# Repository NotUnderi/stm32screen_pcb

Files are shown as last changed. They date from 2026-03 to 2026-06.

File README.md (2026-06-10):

# stm32screen

PCB designed to fit into a 52mm closure and interface with some car sensors and stuff

<b>10.6.2026</b>
<br>
Ordered PCBs from JLCPCB. Changed made to previous version pictured below these new ones are disposing of the USB connector entirely and with it, the SP0503BAHTG TVS diode, adding a user switch, Adding better labels on the silkscreen, slightly better layout, disposing of THT caps. The board will be powered straight from the car's battery, this allows easier installation and decreases cost and complexity.
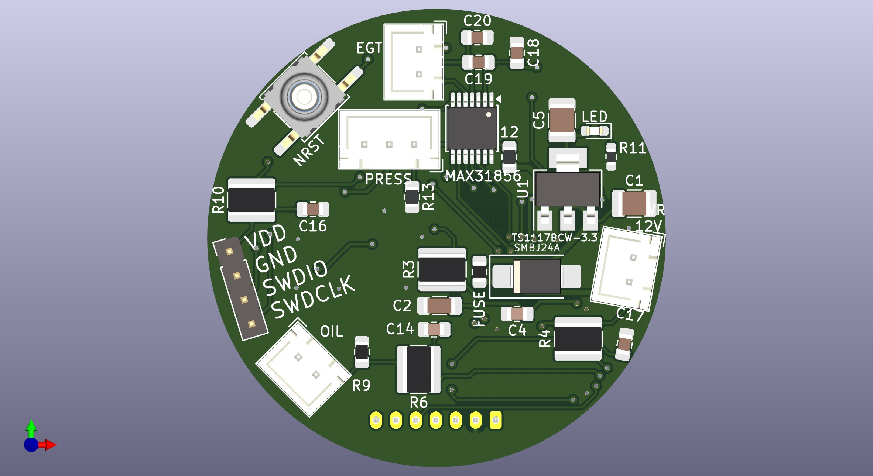
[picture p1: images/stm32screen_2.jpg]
STM32screen PCB F_Cu

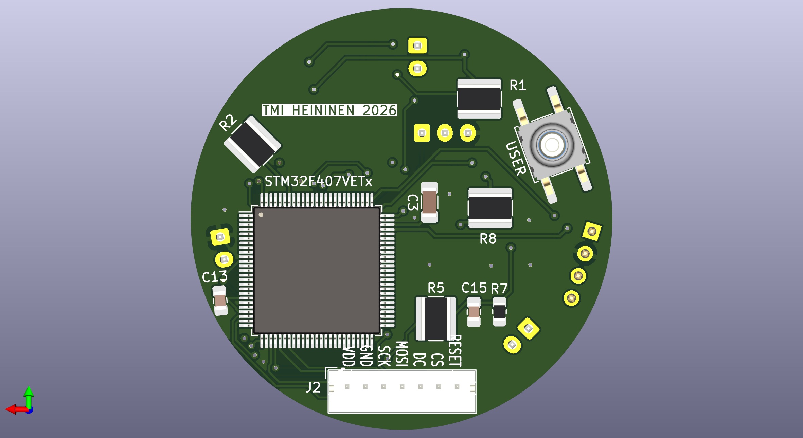
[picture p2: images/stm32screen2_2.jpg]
STM32screen PCB B_Cu


17.3.2026
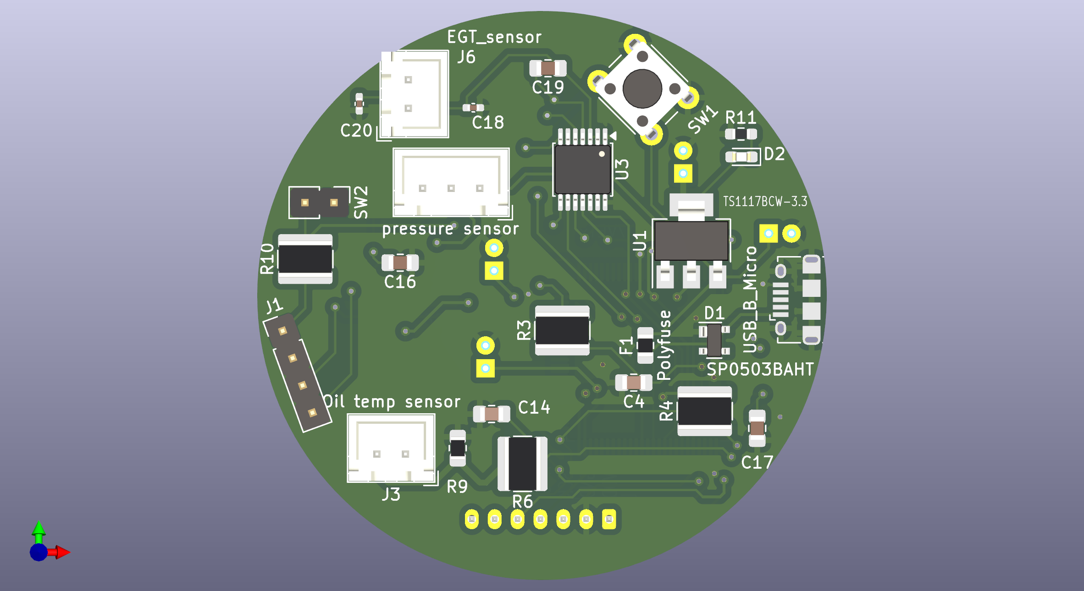
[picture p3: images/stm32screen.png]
STM32screen PCB F_Cu

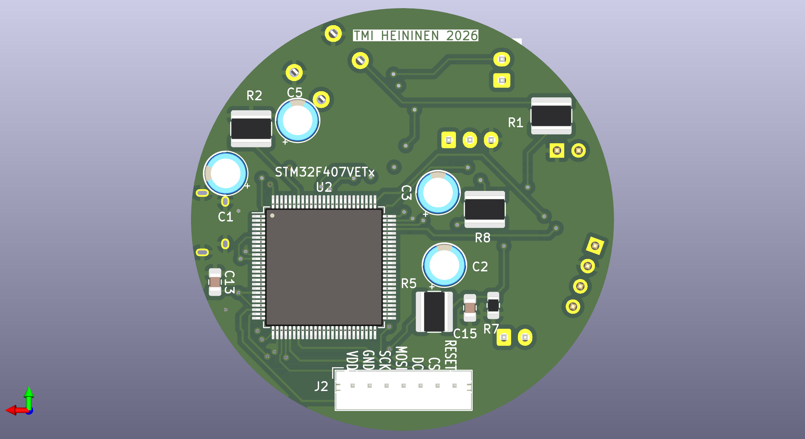
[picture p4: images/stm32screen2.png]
STM32screen PCB B_cu


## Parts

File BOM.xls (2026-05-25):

STM32SCREEN
Mouser No | Mfr. No | Manufacturer | Customer No | Description | RoHS | Lifecycle | Order Qty. | Price (EUR) | Ext.: (EUR)
511-STM32F407VET6 | STM32F407VET6 | STMicroelectronics |  | ARM Microcontrollers - MCU ARM M4 512 FLASH 168 Mhz 192kB SRAM | RoHS Compliant |  | 1 | 9,06 € | 9,06 €
576-SP0503BAHTG | SP0503BAHTG | Littelfuse |  | ESD Protection Diodes / TVS Diodes TVS AVAL DIODE SMT | RoHS Compliant |  | 1 | 0,989 € | 0,99 €
821-TS1117BCW33RPG | TS1117BCW33 RPG | Taiwan Semiconductor |  | LDO Voltage Regulators 1A 3.3V LOW DROPOUT VOLTAGE REGULATOR | RoHS Compliant |  | 1 | 0,327 € | 0,33 €
576-0805L050 | 0805L050WR | Littelfuse |  | Resettable Fuses - PPTC 0.50A 6V 0805 | RoHS Compliant |  | 1 | 2,03 € | 2,03 €
700-MAX31856MUD+ | MAX31856MUD+ | Analog Devices Inc. |  | Sensor Interface Precision Thermocouple to Digital Conver | RoHS Compliant |  | 1 | 11,23 € | 11,23 €
80-C0805F104K1RAUTO | C0805F104K1RACAUTO | KEMET |  | Multilayer Ceramic Capacitors MLCC - SMD/SMT 100V 0.1uF 10% X7R -55 / +125C AEC-Q200 | RoHS Compliant | New Product | 7 | 0,198 € | 1,39 €
71-CRCW121810K0FKEK | CRCW121810K0FKEK | Vishay |  | Thick Film Resistors - SMD 1watt 10Kohms 1% | RoHS Compliant By Exemption |  | 6 | 0,31 € | 1,86 €
71-CRCW1218-10-E3 | CRCW121810R0FKEK | Vishay |  | Thick Film Resistors - SMD 1watt 10ohms 1% | RoHS Compliant By Exemption |  | 2 | 0,43 € | 0,86 €
667-ERA-6APB203V | ERA-6APB203V | Panasonic |  | Thin Film Resistors - SMD 0805 20Kohm 0.1% 15ppm AEC-Q200 | RoHS Compliant |  | 1 | 0,335 € | 0,34 €
594-MCU08050C3300FP5 | MCU08050C3300FP500 | Vishay |  | Thin Film Resistors - SMD MCU 0805-50 1% P5 330R | RoHS Compliant By Exemption |  | 1 | 0,086 € | 0,09 €
179-TS406638R160S | TS40-66-38-R-160-SMT-TR | Same Sky |  | Tactile Switches Tactile Switch, SPST, 6 x 6 mm, 3.8 mm height, 160gf, Red, Surface Mount, TR | RoHS Compliant | New Product | 2 | 0,413 € | 0,83 €
603-SR2512JK-073K3L | SR2512JK-073K3L | YAGEO |  | Thick Film Resistors - SMD 3.3 kOhms 1 W 2512 5 % AEC-Q200 | RoHS Compliant By Exemption |  | 1 | 0,129 € | 0,13 €
720-P4112S2U1252X4X5 | KT EELP41.12-S2U1-25-2X4X-5-R18 | ams OSRAM |  | Single Colour LEDs | RoHS Compliant | New Product | 1 | 0,258 € | 0,26 €
667-ERJ-UP3F1600V | ERJ-UP3F1600V | Panasonic |  | Thick Film Resistors - SMD 0603 0.25W 1% 160ohm AEC-Q200 | RoHS Compliant By Exemption |  | 1 | 0,181 € | 0,18 €
603-CC805KKX5R6BB106 | CC0805KKX5R6BB106 | YAGEO |  | Multilayer Ceramic Capacitors MLCC - SMD/SMT 10V 10uF X5R 0805 10% HI CV | RoHS Compliant |  | 1 | 0,335 € | 0,34 €
77-VJ0805Y103KBBBE31 | VJ0805Y103KBBBE31 | Vishay |  | Multilayer Ceramic Capacitors MLCC - SMD/SMT 0805 10nF 100volts X7R 10% | No |  | 2 | 0,292 € | 0,58 €
603-AA0805FR-134K7L | AA0805FR-134K7L | YAGEO |  | Thick Film Resistors - SMD 4.7k Ohms 1/8 W 0805 1% AEC-Q200 | RoHS Compliant By Exemption |  | 1 | 0,086 € | 0,09 €
910-HDR100IMP40MGVTH | HDR100IMP40M-G-V-TH | Chip Quik |  | PCBs & Breadboards 0.1" 40 pin Vertical Male Header Through Hole Gold | RoHS Compliant |  | 1 | 0,765 € | 0,77 €
306-B7BPHSM4TBLFSN | B7B-PH-SM4-TB(LF)(SN) | JST |  | Headers & Wire Housings PH Series 2 mm Pitch 7 Position SMT Single Row Top Entry Shrouded Header | RoHS Compliant | New Product | 1 | 0,714 € | 0,71 €
306-B2BXHARLFSNP | B2B-XH-A-R(LF)(SN) | JST |  | Headers & Wire Housings XH HEADER (TOP) | RoHS Compliant |  | 3 | 0,138 € | 0,41 €
306-B3BXHAYLFSNP | B3B-XH-A-Y(LF)(SN) | JST |  | Headers & Wire Housings XH HEADER (TOP) | RoHS Compliant | New At Mouser | 1 | 0,181 € | 0,18 €
80-C1206C225K4RAUTO | C1206C225K4RACAUTO | KEMET |  | Multilayer Ceramic Capacitors MLCC - SMD/SMT 16V 2.2uF X7R 1206 10% AEC-Q200 | RoHS Compliant |  | 2 | 0,284 € | 0,57 €

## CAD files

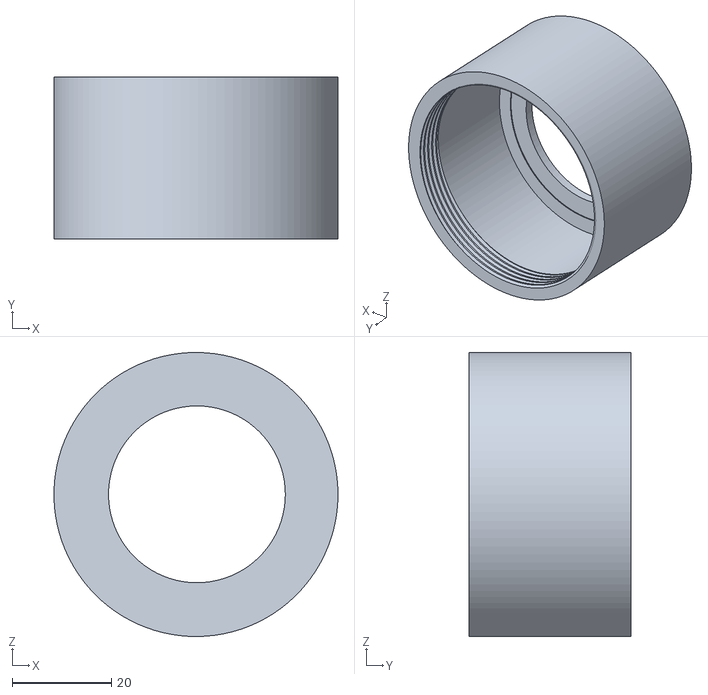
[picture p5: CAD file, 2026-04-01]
case front.stl
57.2 x 32.6 x 57.2

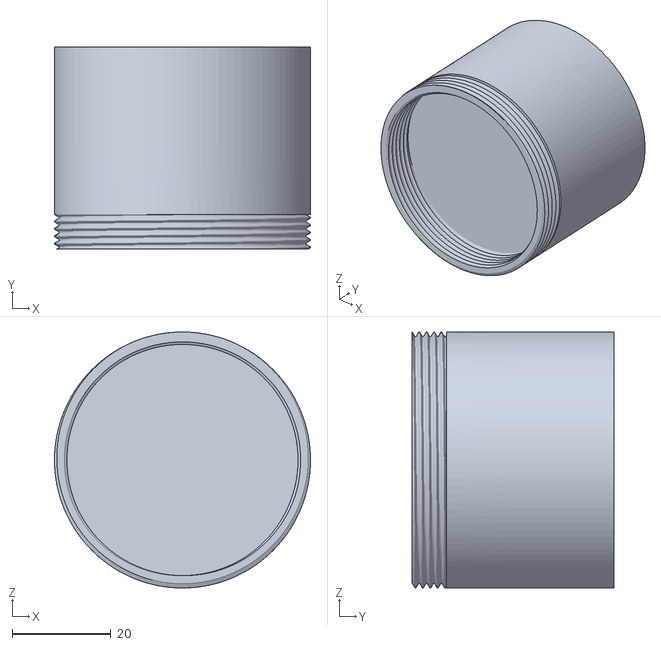
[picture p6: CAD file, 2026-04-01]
case back.stl
51.9 x 41.0 x 51.8

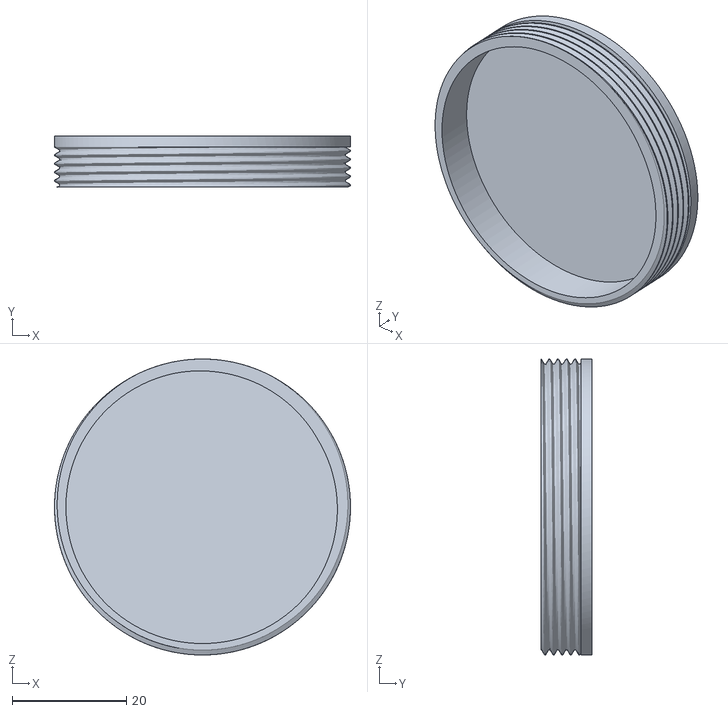
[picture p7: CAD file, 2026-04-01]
case back small.stl
51.8 x 9.00 x 51.8

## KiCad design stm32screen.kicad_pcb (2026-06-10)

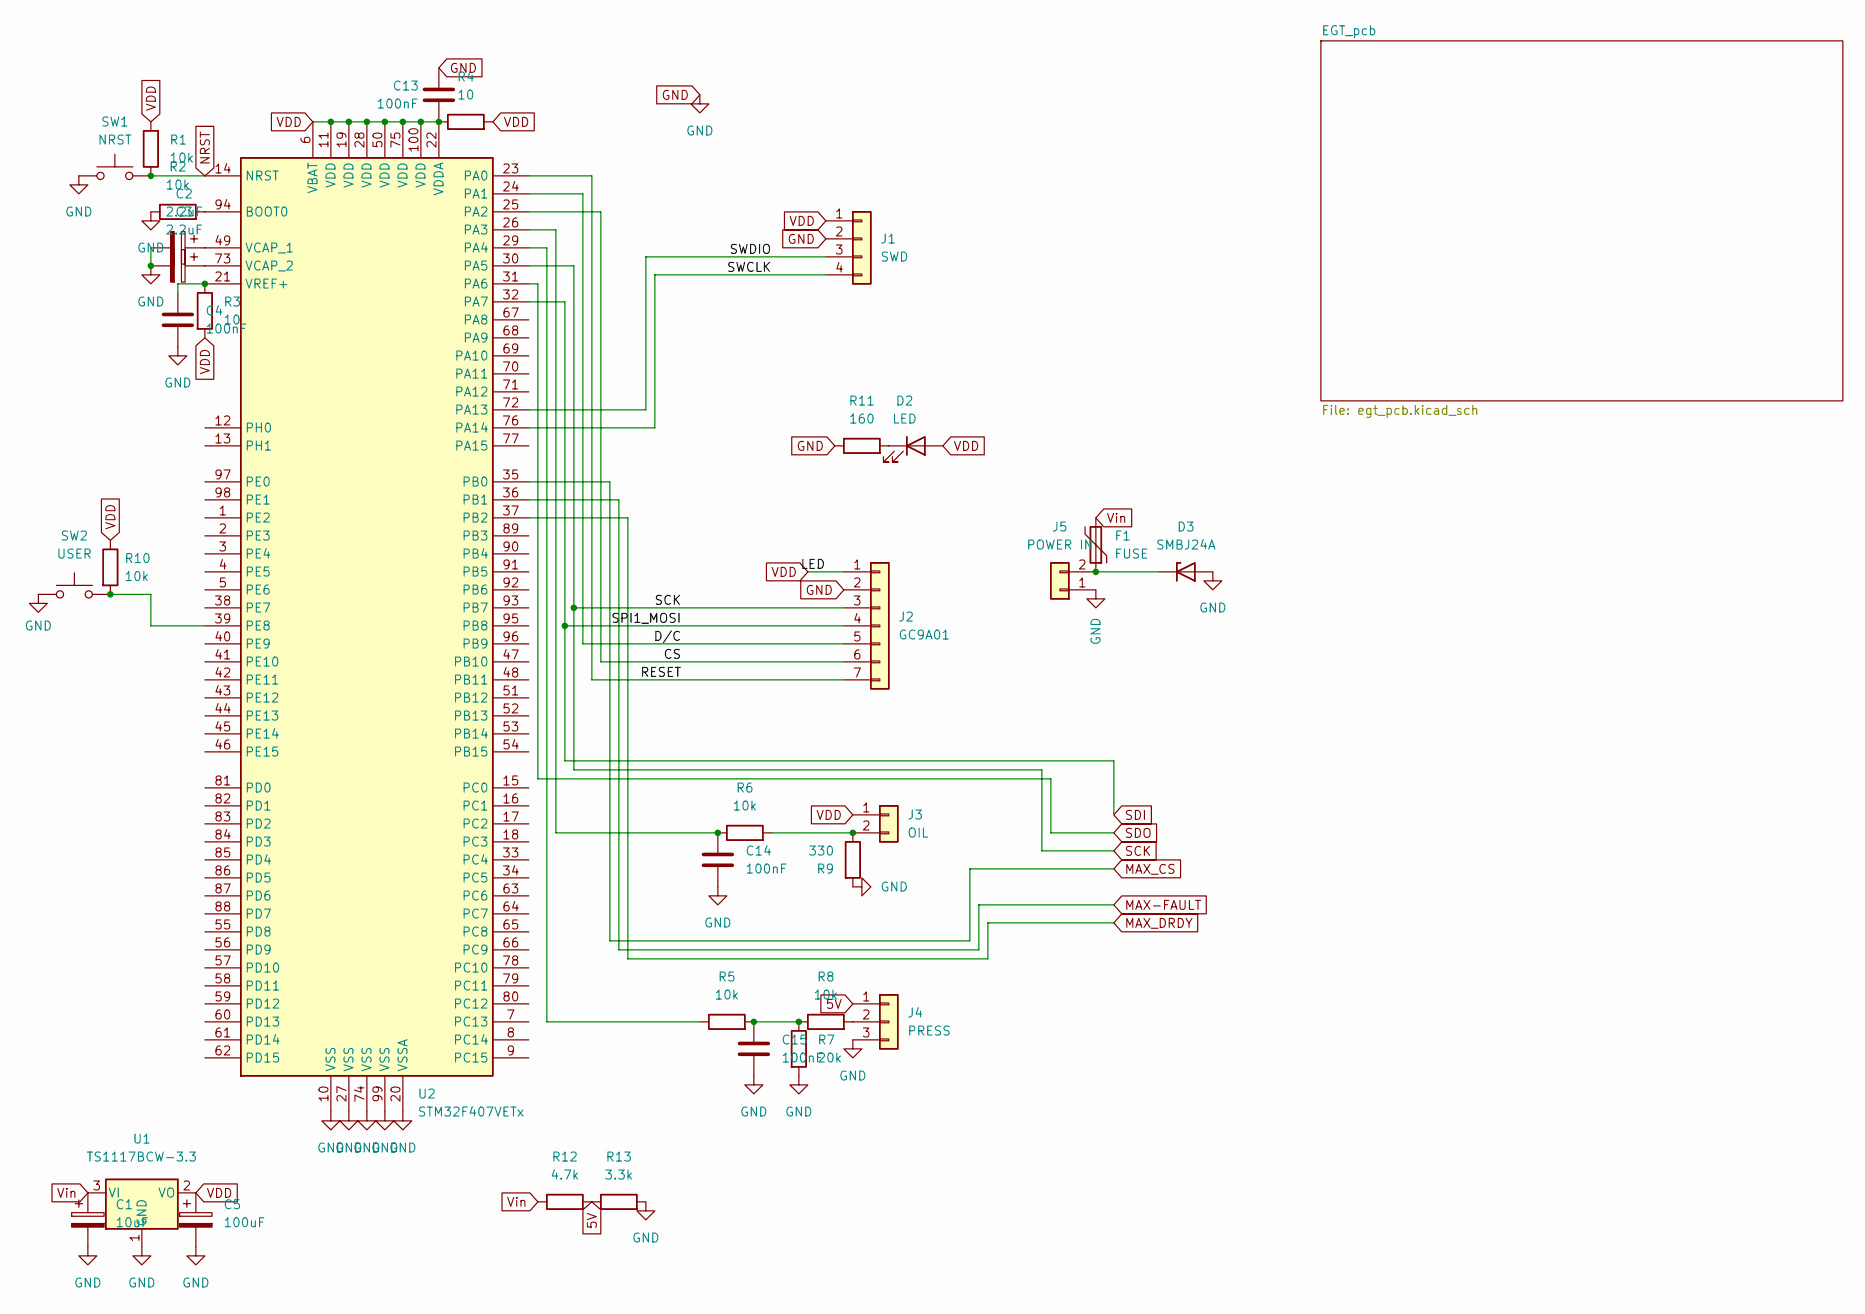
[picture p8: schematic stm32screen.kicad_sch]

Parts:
C1: 10uF; C_1210_3225Metric_Pad1.33x2.70mm_HandSolder
C2, C3: 2.2uF; C_1206_3216Metric_Pad1.33x1.80mm_HandSolder
C4, C13, C14, C15: 100nF; C_0805_2012Metric_Pad1.18x1.45mm_HandSolder
C5: 100uF; C_1210_3225Metric_Pad1.33x2.70mm_HandSolder
D2: LED; LED_0603_1608Metric_Pad1.05x0.95mm_HandSolder
D3: SMBJ24A; D_SMB_Handsoldering
F1: FUSE; Fuse_0805_2012Metric_Pad1.15x1.40mm_HandSolder
J1: SWD; PinHeader_1x04_P2.54mm_Vertical
J2: GC9A01; JST_PH_B7B-PH-K_1x07_P2.00mm_Vertical
J3: OIL; JST_XH_B2B-XH-A_1x02_P2.50mm_Vertical
J4: PRESS; JST_XH_B3B-XH-A_1x03_P2.50mm_Vertical
J5: POWER IN; JST_XH_B2B-XH-A_1x02_P2.50mm_Vertical
R1, R2, R5, R6, R8, R10: 10k; R_1218_3246Metric_Pad1.22x4.75mm_HandSolder
R3, R4: 10; R_1218_3246Metric_Pad1.22x4.75mm_HandSolder
R7: 20k; R_0805_2012Metric_Pad1.20x1.40mm_HandSolder
R9: 330; R_0805_2012Metric_Pad1.20x1.40mm_HandSolder
R11: 160; R_0603_1608Metric_Pad0.98x0.95mm_HandSolder
R12: 4.7k; R_0805_2012Metric_Pad1.20x1.40mm_HandSolder
R13: 3.3k; R_0805_2012Metric_Pad1.20x1.40mm_HandSolder
SW1: NRST; SW_Push_1P1T_NO_CK_KSC9xxG
SW2: USER; SW_Push_1P1T_NO_CK_KSC9xxG
U1: TS1117BCW-3.3; SOT-223-3_TabPin2
U2: STM32F407VETx; LQFP-100_14x14mm_P0.5mm

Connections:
5V: J4.1, R12.2, R13.1
/CS: J2.6, U2.25 (PA2)
/D/C: J2.5, U2.24 (PA1)
/RESET: J2.7, U2.23 (PA0)
/SWCLK: J1.4, U2.76 (PA14)
/SWDIO: J1.3, U2.72 (PA13)
GND: C1.2, C2.2, C3.2, C4.2, C5.2, C13.1, C14.2, C15.2, D3.2 (A), J1.2, J2.2, J4.3, J5.1, R2.1, R7.2, R9.2, R11.1, R13.2, SW1.1, SW2.1, U1.1 (GND), U2.10 (VSS), U2.20 (VSSA), U2.27 (VSS), U2.74 (VSS), U2.99 (VSS); also elsewhere on the board
MAX-FAULT: U2.36 (PB1)
MAX_CS: U2.35 (PB0); also elsewhere on the board
MAX_DRDY: U2.37 (PB2); also elsewhere on the board
NRST: R1.1, SW1.2, U2.14 (NRST)
unnamed: C15.1, R5.2, R7.1, R8.1
unnamed: D2.1 (K), R11.2
unnamed: D3.1 (K), F1.1, J5.2
unnamed: J3.2, R6.2, R9.1
unnamed: J4.2, R8.2
unnamed: R2.2, U2.94 (BOOT0)
unnamed: C14.1, R6.1, U2.26 (PA3)
unnamed: R5.1, U2.29 (PA4)
unnamed: R10.2, SW2.2, U2.39 (PE8)
unnamed: C2.1, U2.49 (VCAP_1)
unnamed: C3.1, U2.73 (VCAP_2)
unnamed: C4.1, R3.1, U2.21 (VREF+)
SCK: J2.3, U2.30 (PA5); also elsewhere on the board
SDI: J2.4, U2.32 (PA7); also elsewhere on the board
SDO: U2.31 (PA6); also elsewhere on the board
VDD: C5.1, C13.2, D2.2 (A), J1.1, J2.1, J3.1, R1.2, R3.2, R4.1, R4.2, R10.1, U1.2 (VO), U2.6 (VBAT), U2.11 (VDD), U2.19 (VDD), U2.22 (VDDA), U2.28 (VDD), U2.50 (VDD), U2.75 (VDD), U2.100 (VDD); also elsewhere on the board
Vin: C1.1, F1.2, R12.1, U1.3 (VI)

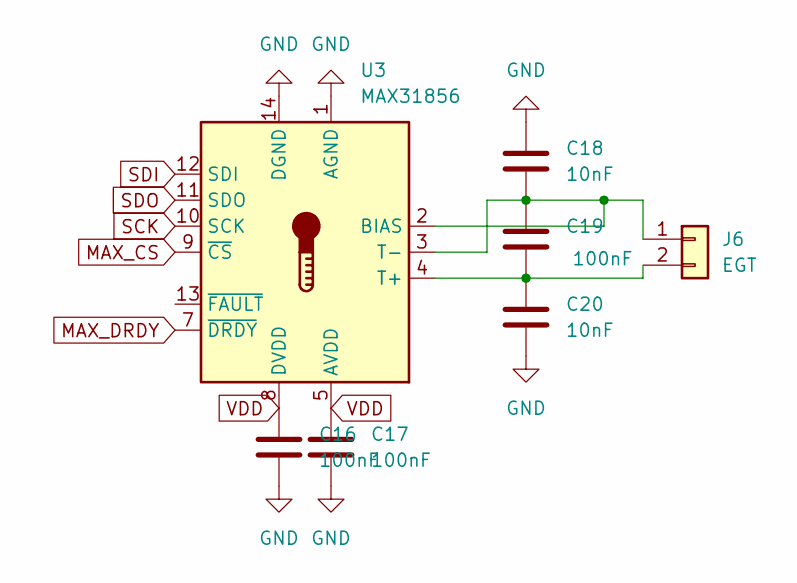
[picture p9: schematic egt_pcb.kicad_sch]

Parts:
C16, C17, C19: 100nF; C_0805_2012Metric_Pad1.18x1.45mm_HandSolder
C18, C20: 10nF; C_0805_2012Metric_Pad1.18x1.45mm_HandSolder
J6: EGT; JST_XH_B2B-XH-A_1x02_P2.50mm_Vertical
U3: MAX31856; TSSOP-14_4.4x5mm_P0.65mm

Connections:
GND: C16.1, C17.1, C18.1, C20.2, U3.1 (AGND), U3.14 (DGND); also elsewhere on the board
MAX_CS: U3.9 (~CS); also elsewhere on the board
MAX_DRDY: U3.7 (~DRDY); also elsewhere on the board
unnamed: C18.2, C19.1, J6.1, U3.2 (BIAS), U3.3 (T-)
unnamed: C19.2, C20.1, J6.2, U3.4 (T+)
SCK: U3.10 (SCK); also elsewhere on the board
SDI: U3.12 (SDI); also elsewhere on the board
SDO: U3.11 (SDO); also elsewhere on the board
VDD: C16.2, C17.2, U3.5 (AVDD), U3.8 (DVDD); also elsewhere on the board

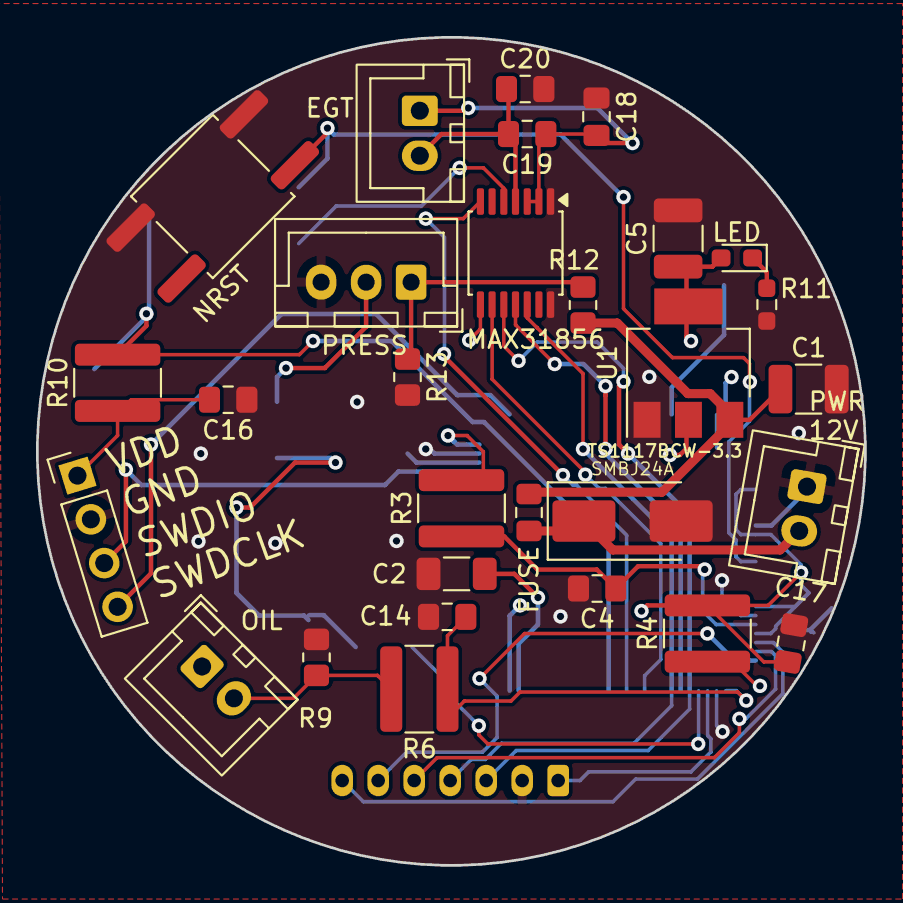
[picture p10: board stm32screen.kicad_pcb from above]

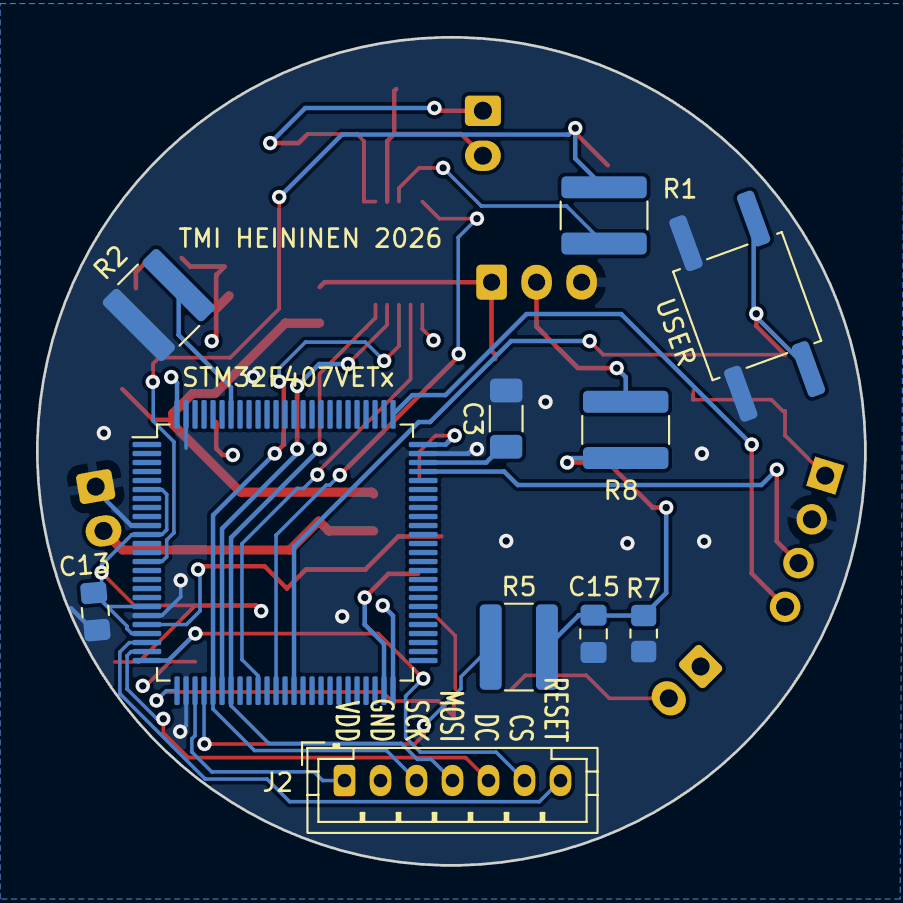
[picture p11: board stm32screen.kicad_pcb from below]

Board: 4 copper layers, 46.0 x 46.0 mm, 40 parts (11 on the bottom side), 29 nets.

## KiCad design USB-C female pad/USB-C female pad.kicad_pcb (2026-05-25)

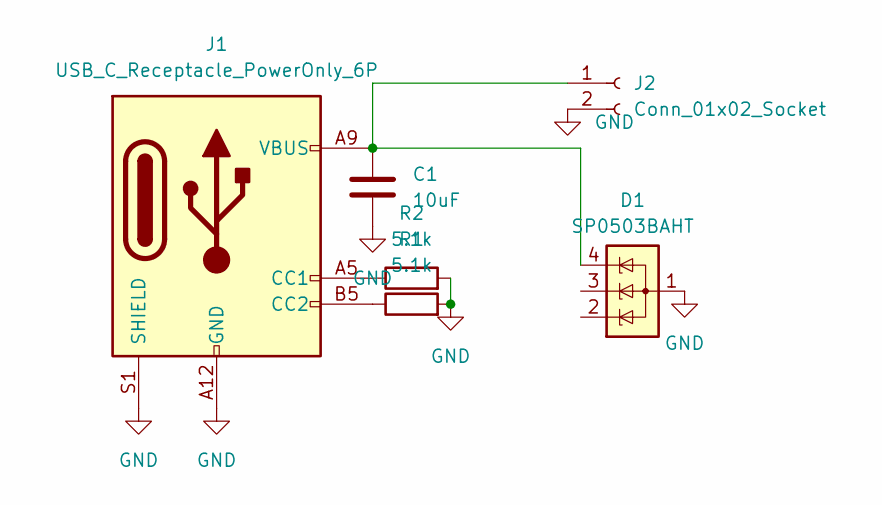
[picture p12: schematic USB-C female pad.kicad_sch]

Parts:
C1: 10uF; C_0805_2012Metric_Pad1.18x1.45mm_HandSolder
D1: SP0503BAHT; SOT-143
J1: USB_C_Receptacle_PowerOnly_6P; USB_C_Receptacle_GCT_USB4135-GF-A_6P_TopMnt_Horizontal
J2: Conn_01x02_Socket; PinHeader_1x02_P2.54mm_Vertical
R1, R2: 5.1k; R_2010_5025Metric_Pad1.40x2.65mm_HandSolder

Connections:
GND: C1.2, D1.1 (A), J1.A12 (GND), J1.B12 (GND), J1.S1 (SHIELD), J2.2, R1.2, R2.2
unnamed: J1.A5 (CC1), R2.1
unnamed: J1.B5 (CC2), R1.1
unnamed: C1.1, D1.4 (K), J1.A9 (VBUS), J1.B9 (VBUS), J2.1

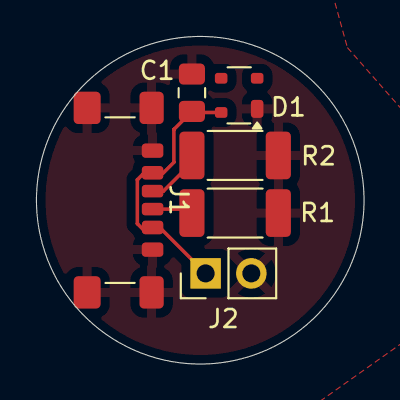
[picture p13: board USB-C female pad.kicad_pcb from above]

Board: 2 copper layers, 18.2 x 18.2 mm, 6 parts (0 on the bottom side), 4 nets.

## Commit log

2026-03-12 Roughing out the PCB.
    [egt_pcb.kicad_sch, stm32screen.kicad_pcb, stm32screen.kicad_sch]
2026-03-12 Routed rest of the unconnected pads
    [stm32screen.kicad_pcb]
2026-03-16 Added a status LED
    [stm32screen.kicad_pcb, stm32screen.kicad_sch]
2026-03-17 Optimized PCB layout. Added images
    [egt_pcb.kicad_sch, stm32screen.kicad_pcb, stm32screen.kicad_sch]
2026-03-17 Update README with PCB images
    Added date and images of the STM32screen PCB.
2026-04-01 Added STL files for the first iteration of cases
    [case back small.stl, case back.stl, case front.stl]
2026-04-01 Changed PCB size to 23mm radius, rearranged parts to fit
    [stm32screen.kicad_pcb, stm32screen.kicad_sch]
2026-04-01 Connected a couple of unconnected pads
    [stm32screen.kicad_pcb]
2026-04-01 Fixed clipping silkscreen
    [stm32screen.kicad_pcb]
2026-04-01 Created a small USB-C PCB to provide portable power on bench
    [USB-C female pad.kicad_pcb, USB-C female pad.kicad_sch]
2026-04-02 Small trace changes
    [USB-C female pad.kicad_pcb, USB-C female pad.kicad_sch, stm32screen.kicad_pcb]
2026-04-16 A bit neater layout. Add missing parts to PCB. Refine silkscreen. New screenshots
    [stm32screen.kicad_pcb]
2026-04-16 THT caps to MLCC as per TS1117B datasheet. STM32 ref caps as well
    [egt_pcb.kicad_sch, stm32screen.kicad_pcb, stm32screen.kicad_sch]
2026-04-16 Adjusted silkscreen and component layout, changed some component values so that silkscreen doesn't change every time
    [stm32screen.kicad_pcb, stm32screen.kicad_sch]
2026-05-25 Add voltage divider for 5v if using 12v in
    [stm32screen.kicad_sch]
2026-05-25 Add SP0503BAHTG to USB-C pad
    [USB-C female pad.kicad_pcb, USB-C female pad.kicad_sch]
2026-05-25 Changed footprints to larger ones and for general unity of footprints
    [egt_pcb.kicad_sch, stm32screen.kicad_pcb, stm32screen.kicad_sch]
2026-05-25 Add BOM with Mouser part numbers
    [BOM.xls]
2026-05-25 Fix missing ground connection for MAX31856
    [stm32screen.kicad_pcb]
2026-05-28 Changed display conn symbol, added NC flags. Corrected silkscreen labels
    [stm32screen.kicad_pcb, stm32screen.kicad_sch]
2026-05-29 Switched from SP0503BAHT to SMBJ24A for a TVS Diode, since we're using 12v supply now instead of 5v
    [stm32screen.kicad_pcb, stm32screen.kicad_sch]
2026-06-07 Ground pour spacing 0.2mm, small trace fixes.
    [stm32screen.kicad_pcb]
2026-06-10 Plot folder changed to project specific. Added pictures of new PCB
    [stm32screen.kicad_pcb]
